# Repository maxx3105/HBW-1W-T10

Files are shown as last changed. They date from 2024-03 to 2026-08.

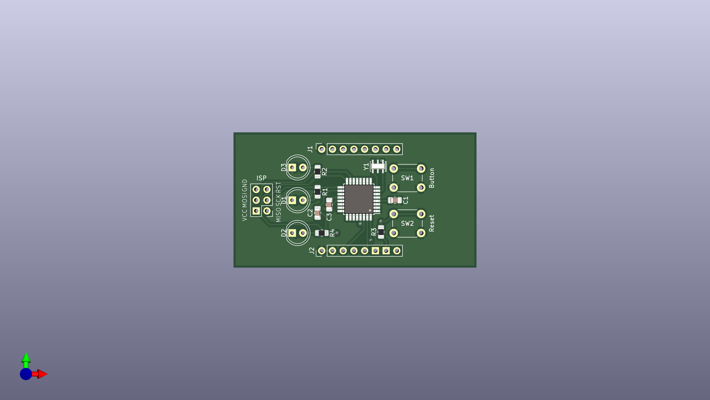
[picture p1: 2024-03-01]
PlatineB_CNMB2/PlatineB_CNMB2.png

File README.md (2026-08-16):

# HBW-1W-T10

10-Kanal-1-Wire-Temperaturmodul für HomeMatic Wired

## Überblick

HomeMatic-Wired-Gerät (RS485) mit bis zu 10 DS18x20-Temperatursensoren an einem
gemeinsamen 1-Wire-Bus. Die Sensoren werden **automatisch erkannt**: Beim Start
scannt das Gerät den Bus, übernimmt die ROM-Adressen jedes gefundenen Fühlers und
legt sie in freie Kanäle. In der CCU wird nur noch eingestellt, wann gesendet wird.

Gerätetyp `0x81`, Aufbau auf zwei Platinen (Hauptplatine und Bedienplatine).

### Basiert auf:
- **HBWired** von Thorsten Pferdekaemper: https://github.com/ThorstenPferdekaemper/HBWired
- Sketch-Vorlage von **loetmeister.de** (Thorsten Pferdekaemper, Dirk Hoffmann)
- Identify-LED nach einer Idee von **jfische**: https://github.com/jfische/HBW-1W-T10

## Aufbau des Repositories

```
HBW-1W-T10/
├── HBW-1W-T10/                  Arduino-Sketch (Ordnername muss zur .ino passen)
│   ├── HBW-1W-T10.ino
│   └── HBW-1W-T10_config.h      Pinbelegung dieser Platine
├── hbw_1w_t10_v1.xml            CCU-Gerätedefinition (hs485types)
├── PlatineA_CNMB2/              KiCad-Projekt Hauptplatine (+ Gerber)
├── PlatineB_CNMB2/              KiCad-Projekt Bedienplatine (+ Gerber)
└── README.md
```

## Hardware

### Unterstützte Sensoren

| Sensor | Family-Code | Auflösung | Genauigkeit |
|---|---|---|---|
| **DS18B20** | 0x28 | 9–12 Bit (Werksvorgabe 12) | ±0,5 °C |
| **DS18S20** / DS1820 | 0x10 | 9 Bit + Extended Resolution | ±0,5 °C |
| **DS1822** | 0x22 | 9–12 Bit | ±2 °C |
| **DS1825** | 0x3B | 9–12 Bit | ±0,5 °C |

Bis zu 10 Fühler parallel an einem Bus (Daten, VCC, GND). DS18S20 wird intern
anders umgerechnet als die übrigen — er liefert 9 Bit in 0,5-°C-Schritten, die
über COUNT_REMAIN auf volle Auflösung hochgerechnet werden.

> **DS1825** setzt einen kleinen Patch in HBWired voraus, siehe [Installation](#2-ds1825-freischalten-optional).

### Bauteile

**PlatineA_CNMB2** (Hauptplatine)
- **ATmega328P-A** mit 16-MHz-Resonator
- **MAX487E** RS485-Transceiver (10 kΩ nach GND an TXEN, damit der Treiber beim
  Reset nicht sendet)
- **MC34063AD** Step-Down-Wandler (24 V Bus → 5 V), 270 µH, SB140
- Feinsicherung 375 mA, SM4007 Verpolschutz
- AVR-ISP-6 Programmierstecker
- Schraubklemmen für 24 V und Bus
- 4,7 kΩ Pull-up am 1-Wire-Bus, 100 kΩ Pull-up am Taster

**PlatineB_CNMB2** (Bedienplatine)
- Status-LED (rot) und Identify-LED (blau), je 470 Ω
- Taster für Config/Werksreset sowie Reset
- Steckverbinder zur Hauptplatine

## Pinbelegung

| Pin | Netz im Schaltplan | Funktion |
|-----|---|---|
| D2 | `TXEN` | RS485 Transmit-Enable |
| D10 | `1WIRE` | 1-Wire-Datenleitung (4,7 kΩ Pull-up nach VCC) |
| D12 / PB4 | `ID_LED` | Identify-LED |
| D13 | `LED` | Status-LED |
| A6 | `Button` | Taster für Config/Werksreset (100 kΩ Pull-up nach VCC, Taster gegen GND) |
| D0 / D1 | `RXD` / `TXD` | UART0 zum MAX487E |

Die SoftwareSerial-Variante von HBWired kommt hier
nicht in Frage (die bräuchte D2 als TX) — das Modul läuft mit
`USE_HARDWARE_SERIAL` über UART0.

**A6** ist beim ATmega328P im TQFP-Gehäuse ein reiner ADC-Eingang: kein
digitaler Eingangspuffer, kein interner Pull-up, `digitalRead()` funktioniert
dort nicht. HBWired erkennt das und fragt den Taster über `analogRead() < 250`
ab (rund 1,22 V bei 5 V), was den externen 100-kΩ-Pull-up auf der Hauptplatine
voraussetzt.

## Funktionsumfang

### Konfiguration je Kanal (in CCU/FHEM)

| Parameter | Bereich | Vorgabe | Bedeutung |
|---|---|---|---|
| **ONEWIRE_TYPE** | NOT_USED / DS18B20 / DS18S20 / DS1822 / DS1825 / REMOVE_SENSOR | NOT_USED | Anzeige des erkannten Sensortyps; `REMOVE_SENSOR` gibt den Kanal wieder frei |
| **SEND_DELTA_TEMP** | 0,1–25,0 °C | 0,5 °C | Sendet, sobald sich die Temperatur um diesen Betrag ändert |
| **OFFSET** | −1,27 bis +1,27 °C | 0,0 °C | Kalibrier-Offset (vorzeichenbehaftet, mit Bias 127 gespeichert) |
| **SEND_MIN_INTERVAL** | 5–3600 s | 10 s | Mindestabstand zwischen zwei Sendungen |
| **SEND_MAX_INTERVAL** | 5–3600 s | 150 s | Spätestens nach dieser Zeit wird gesendet |

### Konfiguration des Geräts

| Parameter | Vorgabe | Bedeutung |
|---|---|---|
| **IDENTIFY_LED** | aus | LED an D12 blinkt im 600-ms-Takt, solange gesetzt — zum Auffinden des Moduls in der Verteilung |
| **OWN_ADDRESS** | 1 | Busadresse des Geräts |

### ONEWIRE_TYPE ist kein Einstellwert

Der Parameter liegt auf dem ersten Byte der 1-Wire-ROM-Adresse — dem Family-Code.
Er zeigt also an, was der Bus-Scan gefunden hat, und wird nicht von Hand gesetzt:
Ein hier eingetragener Typ ändert nur dieses eine Byte, die restlichen sieben
(Seriennummer und CRC) bleiben stehen, und der Kanal spricht danach eine Adresse
an, die es auf dem Bus nicht gibt.

Sinnvoll zu benutzen ist einzig **`REMOVE_SENSOR`**: Das schreibt 0xFF, macht die
gespeicherte Adresse ungültig und gibt den Kanal für einen neuen Fühler frei. Beim
Zurücklesen steht dort anschließend `NOT_USED` — es ist ein einmaliger Befehl,
kein Zustand.

### Ablauf

1. **Bus-Scan** bei jedem Start und nach jedem Konfigurationsschreiben der
   Zentrale: neue Sensoren wandern in freie Kanäle, ihre ROM-Adresse wird ins
   EEPROM übernommen.
2. **Messung**: Alle 1200 ms ist ein Kanal an der Reihe — erst Konvertierung
   anstoßen, im nächsten Durchgang das Ergebnis lesen. Es läuft immer nur eine
   Konvertierung gleichzeitig auf dem gemeinsamen Bus.
3. **Sendeentscheidung**: nie vor SEND_MIN_INTERVAL; gesendet wird bei einer
   Änderung ≥ SEND_DELTA_TEMP oder spätestens nach SEND_MAX_INTERVAL.

Die Kanalzuordnung ergibt sich aus der Reihenfolge, in der die Sensoren beim Scan
gefunden werden — und die hängt an den ROM-Adressen, nicht an der Position im
Strang. Wer eine bestimmte Zuordnung braucht, steckt die Fühler einzeln
nacheinander an oder räumt Kanäle gezielt über `REMOVE_SENSOR` frei.

## Installation

### 1. Arduino-IDE vorbereiten
```bash
git clone https://github.com/maxx3105/HBWired
# nach Arduino/libraries/HBWired kopieren
```

### 2. DS1825 freischalten (optional)

DS18B20, DS18S20 und DS1822 laufen mit HBWired unverändert. Für den **DS1825**
sind zwei kleine Ergänzungen in der Bibliothek nötig, da sie den Family-Code sonst
verwirft:

`libraries/src/HBWOneWireTempSensors.h`
```diff
     static const uint8_t DS18B20_ID = 0x28;
+    static const uint8_t DS1825_ID = 0x3B;
```

`libraries/src/HBWOneWireTempSensors.cpp`
```diff
 bool HBWOneWireTemp::deviceInvalidOrEmptyID(uint8_t deviceType) {
-  return !((deviceType == DS18B20_ID) || (deviceType == DS18S20_ID) || (deviceType == DS1822_ID));
+  return !((deviceType == DS18B20_ID) || (deviceType == DS18S20_ID) || (deviceType == DS1822_ID) ||
+           (deviceType == DS1825_ID));
 };
```

Die Umrechnung braucht keinen eigenen Zweig: Der DS1825 hält seine
Auflösungsbits an derselben Stelle wie der DS18B20 (`data[4] & 0x60`), womit der
bestehende `else`-Zweig greift.

### 3. Übersetzen und flashen

Der Sketch liegt im Unterordner `HBW-1W-T10/` (der Ordnername muss dem
`.ino`-Namen entsprechen).

- `HBW-1W-T10/HBW-1W-T10.ino` in der Arduino-IDE öffnen
- Board: **Arduino Nano** (ATmega328P)
- `HBW-1W-T10_config.h` bildet die Platine ab; `USE_HARDWARE_SERIAL` ist gesetzt.
  Zum Testen auf einem Nano mit Debug-Ausgabe auskommentieren.
- Flashen über ISP

Oder aus dem Projektverzeichnis heraus:

```
arduino-cli compile --fqbn arduino:avr:nano:cpu=atmega328 HBW-1W-T10
arduino-cli compile --fqbn arduino:avr:nano:cpu=atmega328 --upload --programmer usbasp HBW-1W-T10
```

Hinweis: Ist die EESAVE-Fuse nicht gesetzt, löscht jeder ISP-Flash das EEPROM —
und damit die Busadresse und alle gespeicherten Sensoradressen.

### 4. CCU/RaspberryMatic einrichten
1. https://github.com/maxx3105/JP-HB-Devices-addon
2. JP-HB-Devices-addon installieren
3. Gerät an den RS485-Bus anschließen
4. Anlernen und aus dem Posteingang übernehmen

## EEPROM-Belegung

`HBWDevice` liest die Konfigurationsstruktur ab EEPROM-Adresse `0x01`
(siehe `readConfig()` in HBWired.cpp), Struktur-Offset 6 landet also auf `0x07`.

```
0x00      : ungenutzt
0x01      : Logging-Zeit
0x02-0x05 : Zentralen-Adresse
0x06      : Bit 0 Direct-Link-Flag, Bit 1 Identify-LED (invertiert gespeichert)
0x07      : Kanal 1, Konfiguration (14 Byte)
  +0: send_delta_temp
  +1: offset (Bias 127: 0 = −1,27 °C, 127 = 0,00 °C, 254 = +1,27 °C)
  +2-3: send_min_interval (16 Bit, little endian)
  +4-5: send_max_interval (16 Bit, little endian)
  +6-13: 1-Wire-ROM-Adresse; Byte +6 ist der Family-Code = ONEWIRE_TYPE
0x15/0x23/... : Kanal 2..10, Konfiguration (Schrittweite 14), bis 0x92
0x3FC-0x3FF : OWN_ADDRESS (Busadresse, E2END−3 beim 1-kB-EEPROM des 328P)
```

Die Identify-LED wird **invertiert** abgelegt (`boolean_integer invert="true"` in
der XML): Nach einem Werksreset steht das EEPROM auf 0xFF, das Flag also auf 1 —
und die LED bleibt aus. Deshalb heißt das Feld im Sketch `n_identify_led`.

Ein `static_assert` in `HBW-1W-T10.ino` koppelt `ADDRESS_START_CONF_TEMP_CHAN` an
die tatsächliche Position von `TempOWCfg` in der Struktur. Käme ein Feld davor
hinzu, würde `sensorSearch()` sonst still in die Kanalkonfiguration schreiben —
der Build bricht stattdessen ab.

## Fehlersuche

### Sensoren werden nicht gefunden
- Verdrahtung prüfen (3-adrig, kein Parasite-Power-Betrieb vorgesehen)
- Nach dem Anstecken Reset drücken oder in der CCU die Konfiguration schreiben —
  beides löst einen Bus-Scan aus
- Fremde 1-Wire-Bausteine am Bus belegen kurzzeitig einen Kanal, bis ein echter
  Fühler den Platz übernimmt

### Temperatur zeigt −273,15 °C oder −273,14 °C
Das sind die beiden Sonderwerte der Firmware: **−273,15 °C** heißt „Kanal ohne
gültigen Sensor", **−273,14 °C** steht für einen Lese- oder CRC-Fehler, der drei
Versuche überdauert hat — typisch bei abgezogenem Fühler, zu langer Leitung oder
fehlendem Pull-up.

### Falsche Kanalzuordnung
Erwartungsgemäß: Die Reihenfolge kommt vom Bus-Scan, nicht von der Verdrahtung.
Über `REMOVE_SENSOR` einzelne Kanäle freiräumen und die Fühler nacheinander
anstecken.

### Gerät kommuniziert nicht
- RS485-Verdrahtung prüfen (A/B nicht vertauscht)
- Busadresse gesetzt? (`OWN_ADDRESS`, Seriennummer ist 7-Stellig und darf nur einmal am Bus vorhanden sein)
- Ist `USE_HARDWARE_SERIAL` aktiv? Ohne die Option belegt SoftwareSerial D2, das
  auf dieser Platine das Transmit-Enable ist.

### Modul in der Verteilung finden
`IDENTIFY_LED` in der Gerätekonfiguration setzen — die LED an D12 blinkt dann im
600-ms-Takt, bis der Haken wieder entfernt wird.

## Lizenz

Creative Commons BY-NC-SA 3.0 AT
http://creativecommons.org/licenses/by-nc-sa/3.0/at/

## Dank an

- Thorsten Pferdekaemper – HBWired-Framework
- Dirk Hoffmann – Beiträge zu HBWired
- loetmeister.de – Sketch-Vorlage HBW-1W-T10
- jfische – Idee der Identify-LED

## Änderungsverlauf

### v0.06
- 1-Wire-Busarbitrierung repariert: Die Kanäle hielten Zeiger auf lokale
  Variablen von `setup()`, deren Speicher freigegeben wird, sobald `loop()`
  läuft (auch upstream eingereicht:
  [HBWired#47](https://github.com/ThorstenPferdekaemper/HBWired/pull/47))
- `static_assert` koppelt die Kanaladresse an das Struktur-Layout

### v0.05
- DS1825 als vierter Sensortyp

### v0.04
- Identify-LED an D12, schaltbar über den Geräteparameter `IDENTIFY_LED`

### v0.03
- Prüfung auf unterstützte Sensortypen
- Konvertierungs- und Messablauf entzerrt, um falsche Messwerte zu vermeiden

### v0.02
- Start und Fehlerbehandlung bei abgezogenen Sensoren verbessert

### v0.01
- Erste Fassung

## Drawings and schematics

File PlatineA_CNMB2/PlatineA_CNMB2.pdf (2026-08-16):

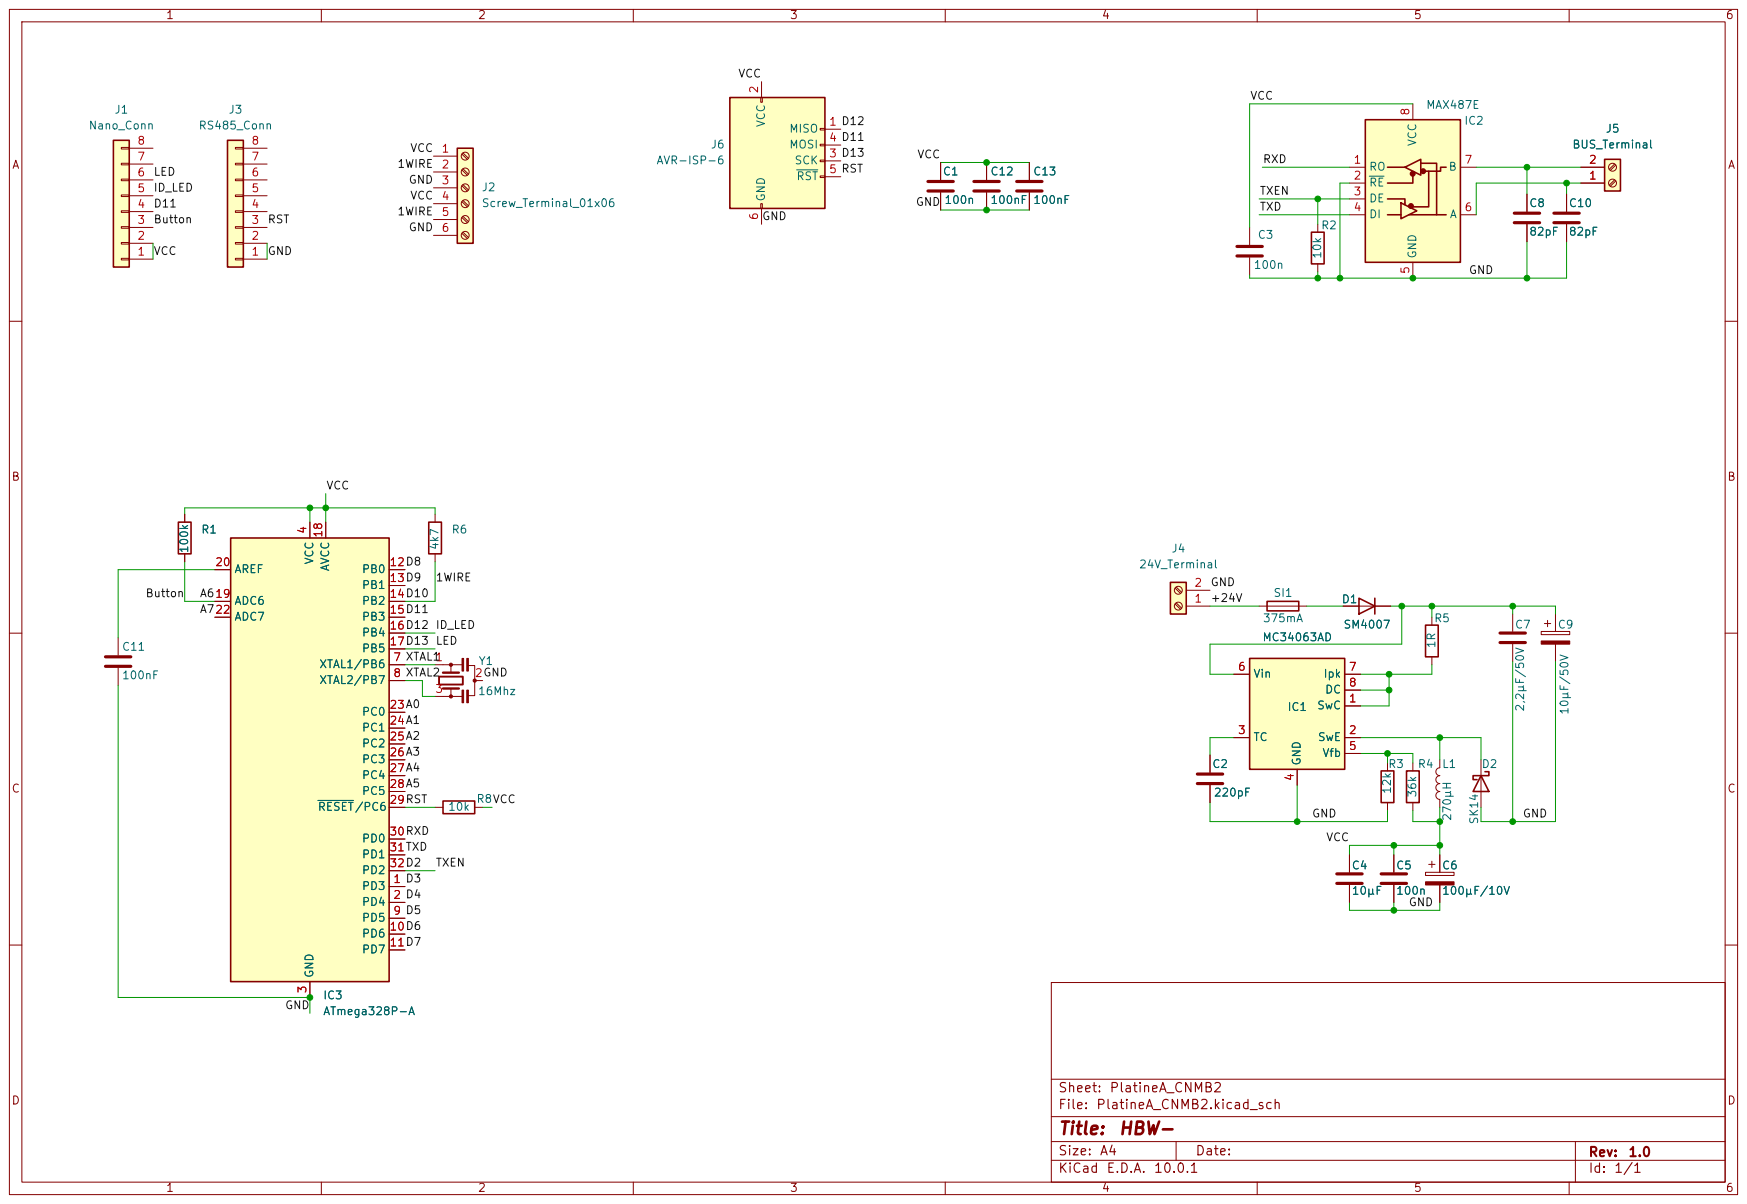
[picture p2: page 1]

Size: A4 | Rev: 1.0
KiCad E.D.A. 10.0.1 | Id: 1/1

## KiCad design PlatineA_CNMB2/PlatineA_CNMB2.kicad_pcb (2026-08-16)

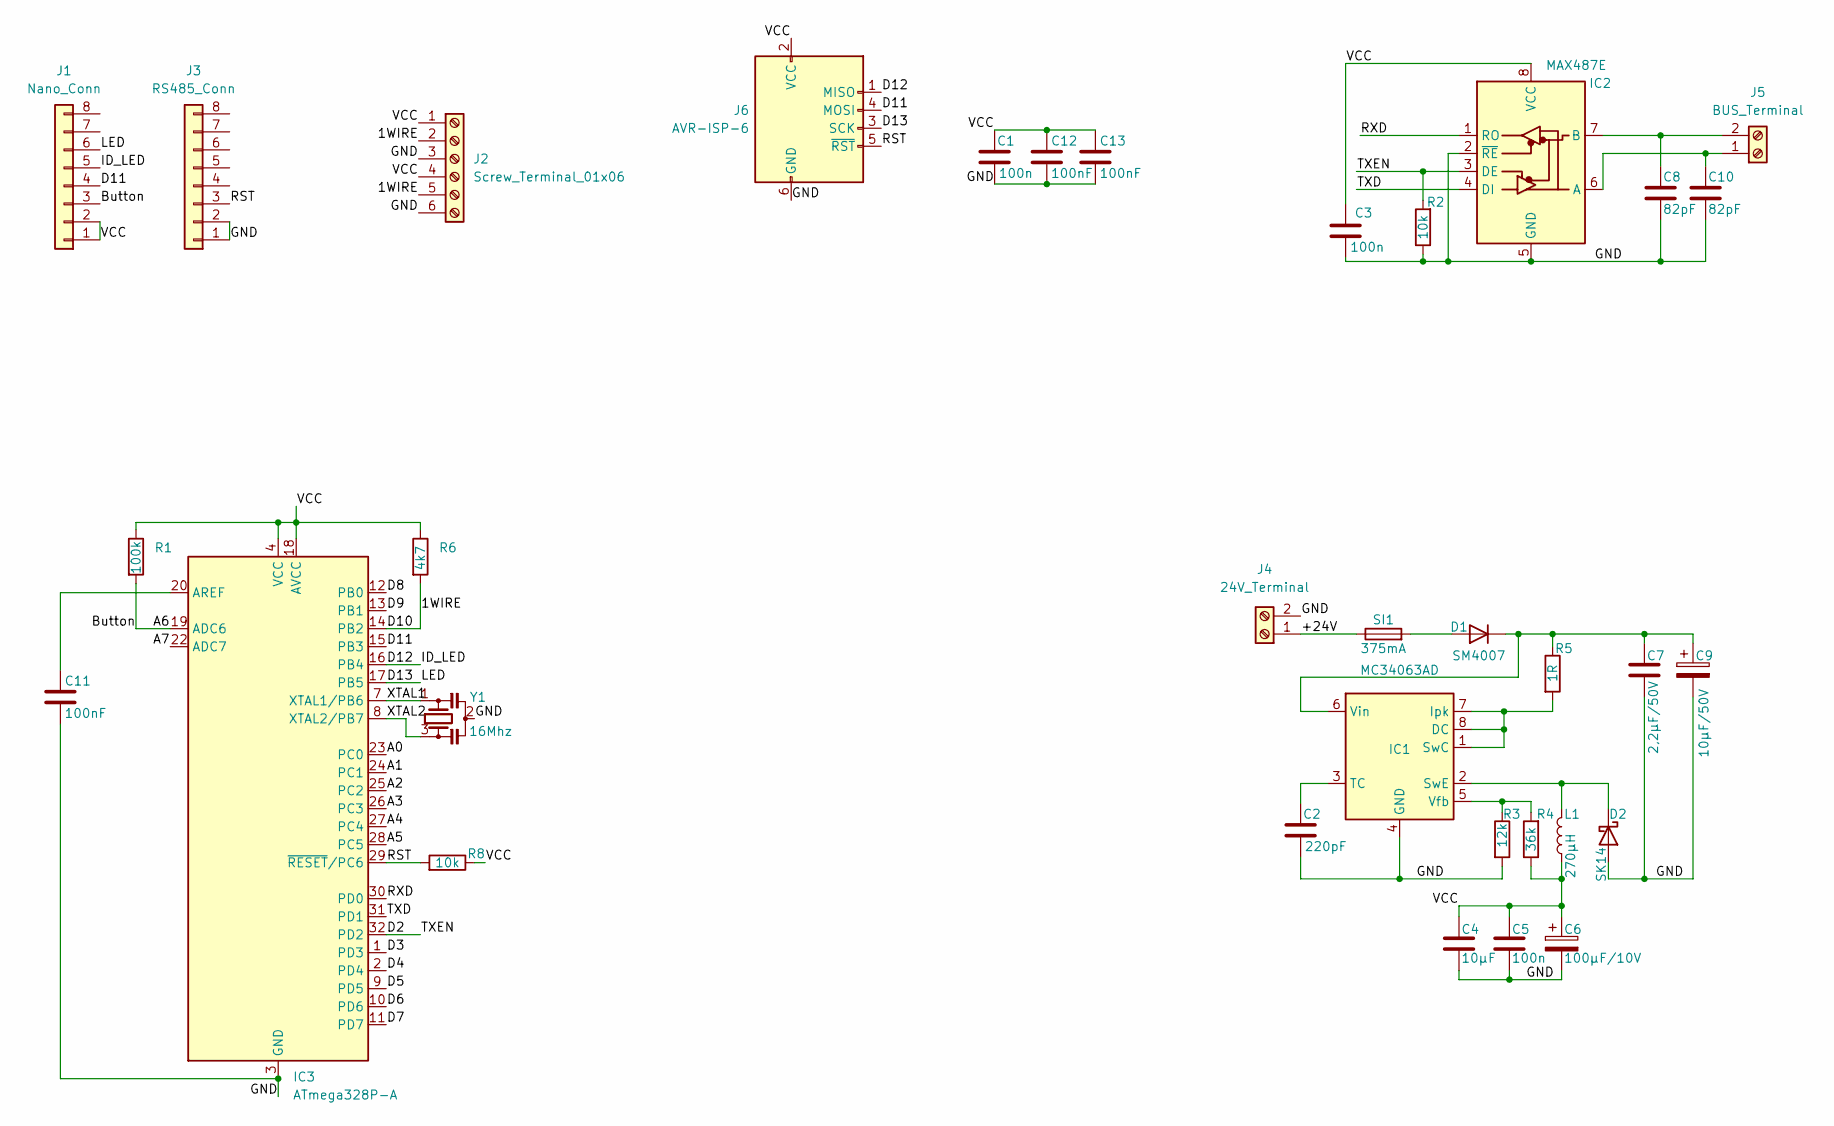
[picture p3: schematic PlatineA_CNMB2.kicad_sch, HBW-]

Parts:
C1, C3, C5: 100n; C_0805_2012Metric_Pad1.18x1.45mm_HandSolder
C2: 220pF; C_0805_2012Metric_Pad1.18x1.45mm_HandSolder
C4: 10µF; C_1210_3225Metric_Pad1.33x2.70mm_HandSolder
C6: 100µF/10V; CP_Radial_D5.0mm_P2.50mm
C7: 2,2µF/50V; C_1210_3225Metric_Pad1.33x2.70mm_HandSolder
C8, C10: 82pF; C_0805_2012Metric_Pad1.18x1.45mm_HandSolder
C9: 10µF/50V; CP_Radial_D5.0mm_P2.50mm
C11, C12, C13: 100nF; C_0805_2012Metric_Pad1.18x1.45mm_HandSolder
D1: SM4007; D_MELF
D2: SK14; D_SMA_Handsoldering
IC1: MC34063AD; SOIC-8_3.9x4.9mm_P1.27mm
IC2: MAX487E; SOIC-8_3.9x4.9mm_P1.27mm
IC3: ATmega328P-A; TQFP-32_7x7mm_P0.8mm
J1: Nano_Conn; PinHeader_1x08_P2.54mm_Vertical
J2: Screw_Terminal_01x06; TerminalBlock_bornier-6_P5.08mm
J3: RS485_Conn; PinHeader_1x08_P2.54mm_Vertical
J4: 24V_Terminal; TerminalBlock_bornier-2_P5.08mm
J5: BUS_Terminal; TerminalBlock_bornier-2_P5.08mm
J6: AVR-ISP-6; PinHeader_2x03_P2.54mm_Vertical
L1: 270µH; L_Taiyo-Yuden_MD-4040
R1: 100k; R_0805_2012Metric_Pad1.20x1.40mm_HandSolder
R2, R8: 10k; R_0805_2012Metric_Pad1.20x1.40mm_HandSolder
R3: 12k; R_0805_2012Metric_Pad1.20x1.40mm_HandSolder
R4: 36k; R_0805_2012Metric_Pad1.20x1.40mm_HandSolder
R5: 1R; R_0805_2012Metric_Pad1.20x1.40mm_HandSolder
R6: 4k7; R_0805_2012Metric_Pad1.20x1.40mm_HandSolder
SI1: 375mA; FUSC6127X294N
Y1: 16Mhz; Resonator_SMD_Murata_CSTxExxV-3Pin_3.0x1.1mm_HandSoldering

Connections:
/1WIRE: IC3.14 (PB2), J2.2, J2.5, R6.2
/+24V: J4.1, SI1.1
/A0: IC3.23 (PC0)
/A1: IC3.24 (PC1)
/A2: IC3.25 (PC2)
/A3: IC3.26 (PC3)
/A4: IC3.27 (PC4)
/A5: IC3.28 (PC5)
/A6: IC3.19 (ADC6), J1.3, R1.2
/A7: IC3.22 (ADC7)
/D2: IC2.3 (DE), IC3.32 (PD2), R2.2
/D3: IC3.1 (PD3)
/D4: IC3.2 (PD4)
/D5: IC3.9 (PD5)
/D6: IC3.10 (PD6)
/D7: IC3.11 (PD7)
/D8: IC3.12 (PB0)
/D9: IC3.13 (PB1)
/D11: IC3.15 (PB3), J1.4, J6.4 (MOSI)
/D12: IC3.16 (PB4), J1.5, J6.1 (MISO)
/D13: IC3.17 (PB5), J1.6, J6.3 (SCK)
/GND: C1.2, C2.2, C3.1, C4.2, C5.1, C6.2, C7.2, C8.2, C9.2, C10.2, C11.1, C12.1, C13.1, D2.2 (A), IC1.4 (GND), IC2.2 (~RE), IC2.5 (GND), IC3.3 (GND), IC3.5 (GND), IC3.21 (GND), J2.3, J2.6, J3.1, J3.2, J4.2, J6.6 (GND), R2.1, R3.2, Y1.2
/RST: IC3.29 (~RESET/PC6), J3.3, J6.5 (~RST), R8.2
/RXD: IC2.1 (RO), IC3.30 (PD0)
/TXD: IC2.4 (DI), IC3.31 (PD1)
/VCC: C1.1, C3.2, C4.1, C5.2, C6.1, C12.2, C13.2, IC2.8 (VCC), IC3.4 (VCC), IC3.6 (VCC), IC3.18 (AVCC), J1.1, J1.2, J2.1, J2.4, J6.2 (VCC), L1.1, R1.1, R4.1, R6.1, R8.1
/XTAL1: IC3.7 (XTAL1/PB6), Y1.1
/XTAL2: IC3.8 (XTAL2/PB7), Y1.3
unnamed: D1.2 (A), SI1.2
unnamed: C7.1, C9.1, D1.1 (K), IC1.6 (Vin), R5.1
unnamed: D2.1 (K), IC1.2 (SwE), L1.2
unnamed: IC1.1 (SwC), IC1.7 (Ipk), IC1.8 (DC), R5.2
unnamed: C2.1, IC1.3 (TC)
unnamed: IC1.5 (Vfb), R3.1, R4.2
unnamed: C10.1, IC2.6 (A), J5.1
unnamed: C8.1, IC2.7 (B), J5.2
unnamed: C11.2, IC3.20 (AREF)

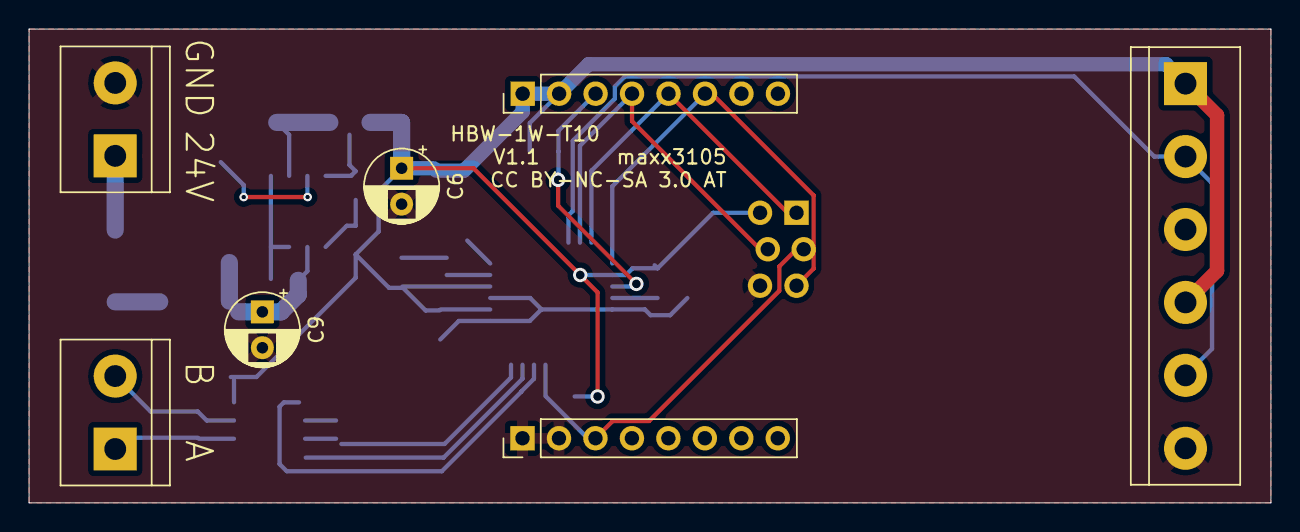
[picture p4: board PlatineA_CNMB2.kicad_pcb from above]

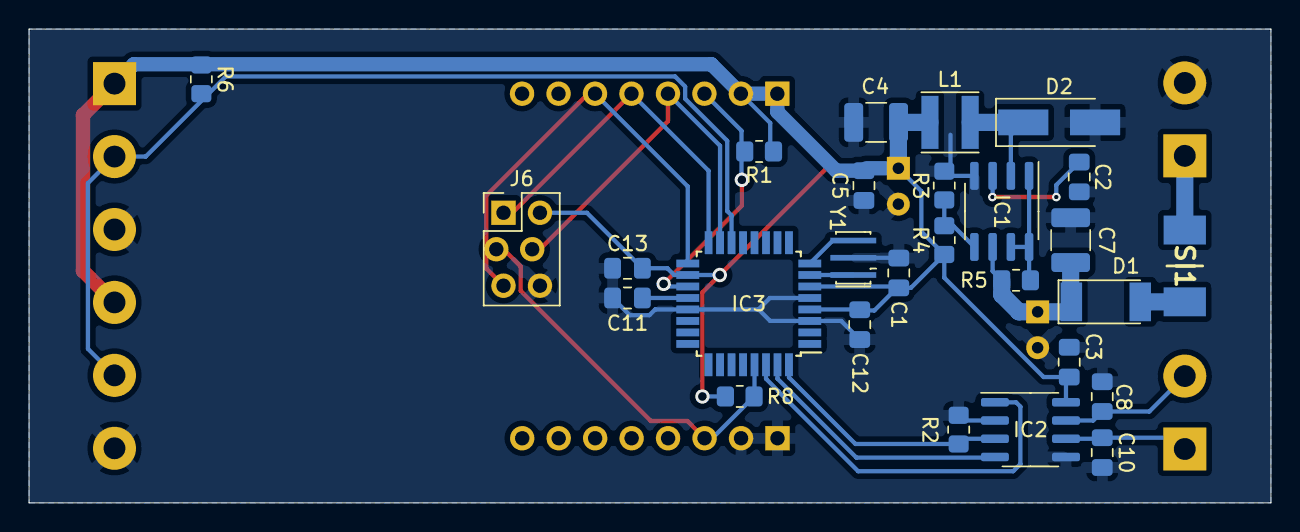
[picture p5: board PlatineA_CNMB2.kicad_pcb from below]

Board: 2 copper layers, 86.5 x 33.0 mm, 34 parts (27 on the bottom side), 23 nets.

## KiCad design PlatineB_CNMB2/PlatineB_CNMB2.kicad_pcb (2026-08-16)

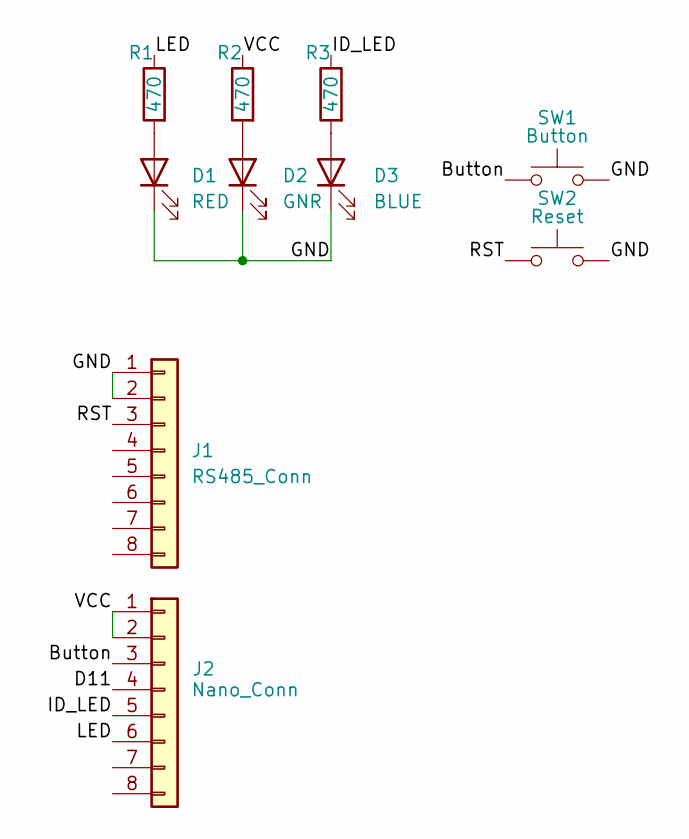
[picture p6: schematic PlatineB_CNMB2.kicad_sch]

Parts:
D1: RED; LED_D5.0mm
D2: GNR; LED_D5.0mm
D3: BLUE; LED_D5.0mm
J1: RS485_Conn; PinHeader_1x08_P2.54mm_Vertical
J2: Nano_Conn; PinSocket_1x08_P2.54mm_Vertical
R1, R2, R3: 470; R_0805_2012Metric_Pad1.20x1.40mm_HandSolder
SW1: Button; SW_PUSH_6mm_H13mm
SW2: Reset; SW_PUSH_6mm_H13mm

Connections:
/Button: J2.3, SW1.1
/D11: J2.4
/GND: D1.1 (K), D2.1 (K), D3.1 (K), J1.1, J1.2, SW1.2, SW2.2
/ID_LED: J2.5, R3.1
/LED: J2.6, R1.1
/RST: J1.3, SW2.1
/VCC: J2.1, J2.2, R2.1
unnamed: D1.2 (A), R1.2
unnamed: D2.2 (A), R2.2
unnamed: D3.2 (A), R3.2

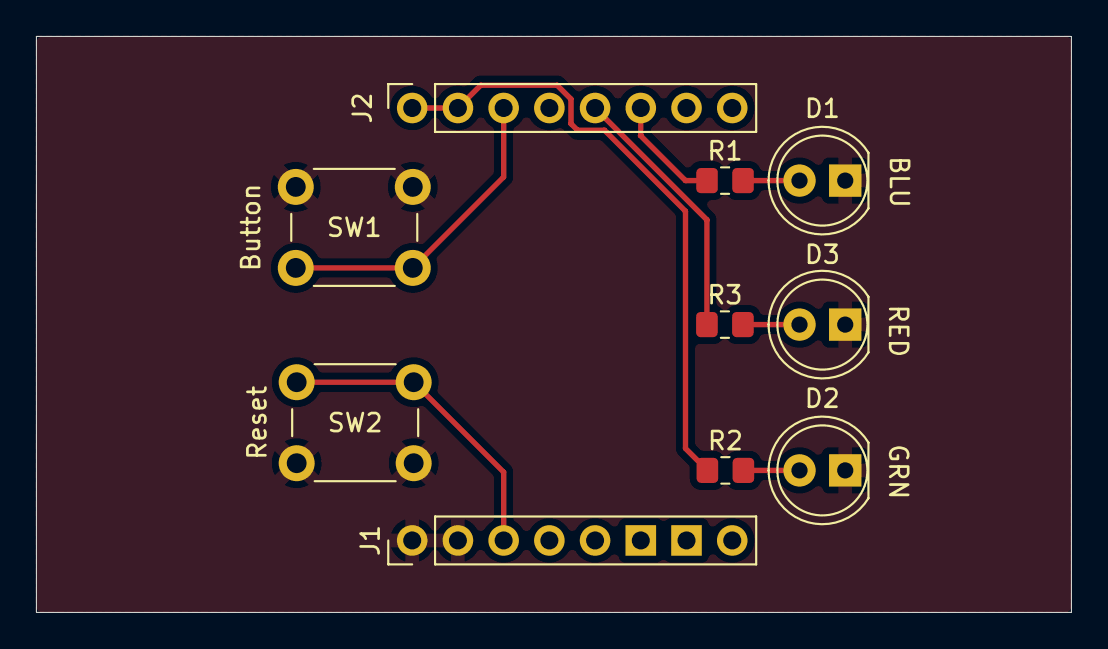
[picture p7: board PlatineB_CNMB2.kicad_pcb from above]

Board: 2 copper layers, 57.5 x 32.0 mm, 10 parts (0 on the bottom side), 9 nets.

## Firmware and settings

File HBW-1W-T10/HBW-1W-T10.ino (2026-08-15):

//*******************************************************************
//
// HBW-1W-T10
//
// Homematic Wired Hombrew Hardware
// Arduino NANO als Homematic-Device
// 
// nach einer Vorlage von
// Thorsten Pferdekaemper (thorsten@pferdekaemper.com), Dirk Hoffmann (hoffmann@vmd-jena.de)
//
// http://loetmeister.de/Elektronik/homematic/index.htm#modules
//
//*******************************************************************
// Changes
// v0.01
// - initial version
// v0.02
// - improved startup and error handling (disconnected sensors)
// v0.03
// - validate supported devices (see HBWOneWireTempSensors.h)
// - optimized conversion and measurement sequence to avoid wrong readings
// v0.04
// - added identify LED (blinks while IDENTIFY_LED is set in the device config)
// v0.05
// - added DS1825 support (see HBWOneWireTempSensors.h)
// v0.06
// - fixed OneWire bus arbitration: the channels held pointers to setup() stack
//   variables, which got overwritten as soon as loop() ran


#define HARDWARE_VERSION 0x01
#define FIRMWARE_VERSION 0x0006
#define HMW_DEVICETYPE 0x81 //device ID (make sure to import hbw_1w_t10_v1.xml into FHEM)

#define IDENTIFY_LED_INTERVAL 600   // blink interval of the identify LED in ms

#define NUMBER_OF_TEMP_CHAN 10   // input channels - 1-wire temperature sensors
#define ADDRESS_START_CONF_TEMP_CHAN 0x7  // first EEPROM address for temperature sensors configuration
//#define NUM_LINKS_TEMP 30    // requires Support_HBWLink_InfoEvent in HBWired.h
#define LINKADDRESSSTART_TEMP 0xE6   // step 6


// HB Wired protocol and module
#include <HBWired.h>
#include <HBWOneWireTempSensors.h>
#include <HBWLinkInfoEventSensor.h>
#include <HBW_eeprom.h>


// Pins and hardware config
#include "HBW-1W-T10_config.h"  // pinout of this board - see README (derived from Platine2 schematic)


#define NUMBER_OF_CHAN NUMBER_OF_TEMP_CHAN


struct hbw_config {
  uint8_t logging_time;     // 0x01
  uint32_t central_address;  // 0x02 - 0x05
  uint8_t direct_link_deactivate:1;   // 0x06:0
  uint8_t n_identify_led:1;  // 0x06:1  0=identify LED active (blinking), 1=off
  uint8_t              :6;   // 0x06:2-7
  hbw_config_onewire_temp TempOWCfg[NUMBER_OF_TEMP_CHAN]; // 0x07 - 0x.. (address step 14)
} hbwconfig;

/* sensorSearch() writes the sensor IDs into the EEPROM using ADDRESS_START_CONF_TEMP_CHAN.
 * That constant must match where TempOWCfg actually sits in the config struct - the struct
 * is read from EEPROM 0x01, so struct offset 6 equals EEPROM address 0x07. Adding a field
 * in front of TempOWCfg would silently shift the channel config. */
static_assert(offsetof(hbw_config, TempOWCfg) +1 == ADDRESS_START_CONF_TEMP_CHAN,
              "ADDRESS_START_CONF_TEMP_CHAN does not match the config struct layout");


HBWChannel* channels[NUMBER_OF_CHAN];  // total number of channels for the device

hbw_config_onewire_temp* tempConfig[NUMBER_OF_TEMP_CHAN]; // global pointer for OneWire channels config


class HBTempOWDevice : public HBWDevice {
    public:
    HBTempOWDevice(uint8_t _devicetype, uint8_t _hardware_version, uint16_t _firmware_version,
               Stream* _rs485, uint8_t _txen, 
               uint8_t _configSize, void* _config, 
               uint8_t _numChannels, HBWChannel** _channels,
               Stream* _debugstream, HBWLinkSender* linksender = NULL, HBWLinkReceiver* linkreceiver = NULL,
               OneWire* oneWire = NULL, hbw_config_onewire_temp** _tempSensorconfig = NULL) :
    HBWDevice(_devicetype, _hardware_version, _firmware_version,
              _rs485, _txen, _configSize, _config, _numChannels, ((HBWChannel**)(_channels)),
              _debugstream, linksender, linkreceiver)
              {
                d_ow = oneWire;
                tempSensorconfig = _tempSensorconfig;
    };
    virtual void afterReadConfig();
    
    private:
      OneWire* d_ow;
      hbw_config_onewire_temp** tempSensorconfig;
};

// device specific defaults
void HBTempOWDevice::afterReadConfig()
{
  HBWOneWireTemp::sensorSearch(d_ow, tempSensorconfig, (uint8_t) NUMBER_OF_TEMP_CHAN, (uint8_t) ADDRESS_START_CONF_TEMP_CHAN);
};

HBTempOWDevice* device = NULL;


#ifdef IDENTIFY_LED
// Identify LED, to locate the device inside a distribution board. Blinks as long as
// IDENTIFY_LED is set in the device config. 'n_identify_led' is stored inverted
// (see hbw_1w_t10_v1.xml: boolean_integer invert="true"), so the LED stays off with
// blank EEPROM (0xFF) after a factory reset.
void identifyLedLoop()
{
  static uint32_t lastTime = 0;
  uint32_t now = millis();

  if (hbwconfig.n_identify_led) {
    digitalWrite(IDENTIFY_LED, LOW);
    lastTime = now;
  }
  else if (now - lastTime >= IDENTIFY_LED_INTERVAL) {
    digitalWrite(IDENTIFY_LED, !digitalRead(IDENTIFY_LED));
    lastTime = now;
  }
};
#endif


void setup()
{
#ifdef IDENTIFY_LED
  pinMode(IDENTIFY_LED, OUTPUT);
  digitalWrite(IDENTIFY_LED, LOW);
#endif

  // variables for all OneWire channels
  // must be static: the channels keep pointers to them, so they have to outlive setup()
  OneWire* g_ow = new OneWire(ONEWIRE_PIN);
  static uint32_t g_owLastReadTime = 0;
  static uint8_t g_owCurrentChannel = OW_CHAN_INIT; // always init with OW_CHAN_INIT! used as trigger/reset in channel loop()

  // create channels
  for(uint8_t i = 0; i < NUMBER_OF_TEMP_CHAN; i++) {
    channels[i] = new HBWOneWireTemp(g_ow, &(hbwconfig.TempOWCfg[i]), &g_owLastReadTime, &g_owCurrentChannel);
    tempConfig[i] = &(hbwconfig.TempOWCfg[i]);
  }


#ifdef USE_HARDWARE_SERIAL  // RS485 via UART Serial, no debug (_debugstream is NULL)
  Serial.begin(19200, SERIAL_8E1);
  
  device = new HBTempOWDevice(HMW_DEVICETYPE, HARDWARE_VERSION, FIRMWARE_VERSION,
                             &Serial, RS485_TXEN, sizeof(hbwconfig), &hbwconfig,
                             NUMBER_OF_CHAN, (HBWChannel**)channels,
                             NULL,
  #if defined(NUM_LINKS_TEMP)
                             new HBWLinkInfoEventSensor<NUM_LINKS_TEMP, LINKADDRESSSTART_TEMP>(), NULL,
  #else
                             NULL, NULL,
  #endif
                             g_ow, tempConfig);
  
  device->setConfigPins(BUTTON, LED);  // use analog input for 'BUTTON'
  //device->setStatusLEDPins(LED, LED); // Tx, Rx LEDs
  
#else
  Serial.begin(115200);  // Serial->USB for debug
  rs485.begin(19200);   // RS485 via SoftwareSerial, must use 19200 baud!
  
  device = new HBTempOWDevice(HMW_DEVICETYPE, HARDWARE_VERSION, FIRMWARE_VERSION,
                             &rs485, RS485_TXEN, sizeof(hbwconfig), &hbwconfig,
                             NUMBER_OF_CHAN, (HBWChannel**)channels,
                             &Serial,
  #if defined(NUM_LINKS_TEMP)
                             new HBWLinkInfoEventSensor<NUM_LINKS_TEMP, LINKADDRESSSTART_TEMP>(), NULL,
  #else
                             NULL, NULL,
  #endif
                             g_ow, tempConfig);
  
  device->setConfigPins(BUTTON, LED);  // 8 (button) and 13 (led) is the default
  // device->setStatusLEDPins(LED, LED); // Tx, Rx LEDs

  hbwdebug(F("B: 2A "));
  hbwdebug(freeRam());
  hbwdebug(F("\n"));
#endif
}


void loop()
{
  device->loop();
#ifdef IDENTIFY_LED
  identifyLedLoop();
#endif
};


// check if HBWLinkInfoEvent support is enabled, when links are set
#if !defined(Support_HBWLink_InfoEvent) && defined(NUM_LINKS_TEMP)
#error enable/define Support_HBWLink_InfoEvent in HBWired.h
#endif
  

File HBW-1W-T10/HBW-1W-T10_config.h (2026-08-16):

/* Pinout of this board (see Platine2 schematic). The generic example that ships with
 * HBWired is HBW-1W-T10_config_example.h - this file replaces it for this hardware. */

// ATmega328P-A with 16 MHz resonator, RS485 via MAX487E on Platine1.

EEPROMClass* EepromPtr = &EEPROM;  // use internal EEPROM

/* The board wires UART0 straight to the MAX487E and uses D2 as transmit enable,
 * so the SoftwareSerial variant (which would need D2 for TX) does not apply here.
 * Comment this out only for bench testing with a Nano, then RS485 moves to
 * SoftwareSerial and UART0 becomes the debug output. */
#define USE_HARDWARE_SERIAL

/* Undefine "HBW_DEBUG" in 'HBWired.h' to remove unneeded code. "HBW_DEBUG" also works as
 * master switch, as hbwdebug() or hbwdebughex() used in channels will point to empty functions. */

// Pins
#ifdef USE_HARDWARE_SERIAL
  #define RS485_TXEN 2  // D2  - Transmit-Enable (schematic net "TXEN")
  #define BUTTON A6     // A6  - Button fuer Factory-Reset etc. (schematic net "Button")
  #define LED 13        // D13 - Signal-LED
  #define IDENTIFY_LED 12  // D12/PB4 - Identify-LED (schematic net "ID_LED"), auskommentieren wenn nicht bestueckt

  #define ONEWIRE_PIN	10 // D10 - Onewire Bus (schematic net "1WIRE", 4k7 pullup on board)

#else
  // bench setup on an Arduino Nano, RS485 via SoftwareSerial, UART0 = debug
  #define RS485_RXD 4
  #define RS485_TXD 2
  #define RS485_TXEN 3
  #define BUTTON 5
  #define LED 13
  #define IDENTIFY_LED 12

  #define ONEWIRE_PIN	10

  #include "FreeRam.h"
  #include <HBWSoftwareSerial.h>
  HBWSoftwareSerial rs485(RS485_RXD, RS485_TXD); // RX, TX
#endif  //USE_HARDWARE_SERIAL

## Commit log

2024-03-19 Change button from A6 to D5
    [HBW-1W-T10-Platine2-B_Cu.gbr, HBW-1W-T10-Platine2-B_Mask.gbr, HBW-1W-T10-Platine2-B_Paste.gbr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]
2026-08-15 Sketch, CCU-XML und ausführliche README ergänzen
    Bisher lagen hier nur die KiCad-Projekte. Ergänzt:
    - HBW-1W-T10/ - Arduino-Sketch (v0.06) mit HBW-1W-T10_config.h, dessen Pins
    aus dem Schaltplan von Platine2 stammen: TXEN=D2, Button=D5, OneWire=D10,
    ID_LED=D12. Weil D2 das Transmit-Enable ist, scheidet die
    SoftwareSerial-Variante aus - das Modul läuft über UART0.
    - hbw_1w_t10_v1.xml - Gerätedefinition für die CCU
    - README nach dem Muster von HBW-Sen-PRESS
    Enthaltene Änderungen gegenüber der loetmeister-Vorlage: Identify-LED an D12
    (Geräteparameter IDENTIFY_LED, invertiert auf 0x06 Bit 1), DS1825 als vierter
    Sensortyp, Fix der 1-Wire-Busarbitrierung (Zeiger auf setup()-Stack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
    [HBW-1W-T10.ino, HBW-1W-T10_config.h]
2026-08-15 Revise reset button description and update repo link
    Updated README to reflect changes in reset button functionality and repository link.
2026-08-16 Add files via upload
    V1.1
    [PlatineA_CNMB2-B_Cu.gbr, PlatineA_CNMB2-B_Mask.gbr, PlatineA_CNMB2-B_Paste.gbr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]
2026-08-16 Change BUTTON pin from D5 to A6
2026-08-16 README an die neuen Platinen anpassen
    Nachzug auf PlatineA_CNMB2 / PlatineB_CNMB2 und den Taster auf A6:
    - Repo-Baum und Bauteilliste: Hauptplatine (ATmega328P-A, MAX487E, MC34063AD,
    ISP, Klemmen) und Bedienplatine (2 LEDs, 2 Taster)
    - Pinbelegung: Taster jetzt A6 statt D5, Netzname des 1-Wire-Busses ist 1WIRE
    - Absatz dazu, warum A6 den externen 100k-Pull-up braucht: reiner ADC-Eingang
    ohne internen Pull-up, HBWired fragt ihn per analogRead() < 250 ab
    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

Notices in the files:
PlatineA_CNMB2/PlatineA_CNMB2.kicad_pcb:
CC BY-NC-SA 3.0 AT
